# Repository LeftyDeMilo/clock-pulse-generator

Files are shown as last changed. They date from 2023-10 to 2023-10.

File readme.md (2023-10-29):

Breadboard Clock Pulse Generator with manual and automatic operating modes.
In manual mode the circuit operates as a debounced button. In automatic mode
it operates as a square wave generator. You could bear through a preset list
of frequencies in a range from 0.1 Hz to 97 Hz.

# Terminal

To check ATtiny24 fuses (and the MCU reaction) you could use `avrdude`.

```sh
$ avrdude -p t24 -c usbasp
```

Brandnew ATtiny24 _20SSU_ responses `Fuses OK (E:FF, H:DC, L:E2)`,
_20PU_ – `Fuses OK (E:FF, H:DF, L:62)`.

Preset fuses:

```sh
$ avrdude -p t24 -c usbasp -U lfuse:w:0xE2:m -U hfuse:w:0xDD:m -U efuse:w:0xFE:m
```

# Arduino IDE

Choose the proper MCU:

Tools > Board > DIY ATtiny > ATtiny24

Choose the compilation settings

Tools >

* Use Bootloader: "No (ISP Programmer Upload)"
* Processor Speed: "8MHz Internal Oscillator"
* Millis, Tone Support: "Millis Available, No Tone"
* Millis Accuracy: "Better Or Equal 0.1% Error (Highest Code Use)"
* Processor Version: "ATtiny24"
* Programmer: "DIY ATTiny: USBasp"

Upload sketch through ICSP connector using USBasp programmer:

Sketch > Upload Using Programmer

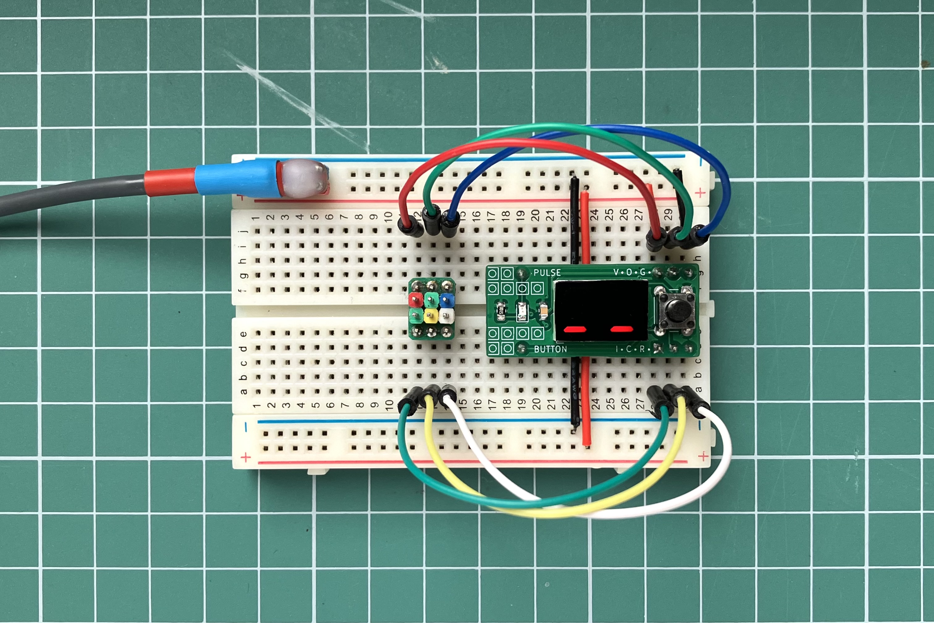
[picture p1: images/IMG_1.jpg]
ICSP Breakout Set


# Operating Manual

Use double click to change operating mode. In both modes an LED indicates a
voltage level on the PULSE pin.

### Manual mode

In manual mode the device operates as a debounced button. The seven segment
display indicates a voltage level on the PULSE pin (like an oscilloscope).

### Automatic Pulse Mode

In automatic pulse mode the display indicates a current pulse frequency.
You could bear though frequencies with a long button click.

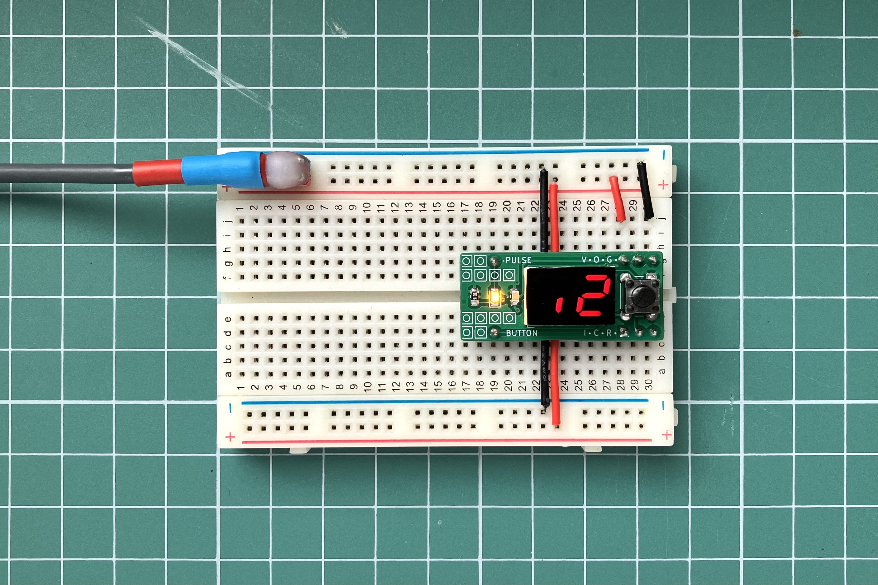
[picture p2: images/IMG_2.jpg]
Square wave pulse of 0.2 Hz


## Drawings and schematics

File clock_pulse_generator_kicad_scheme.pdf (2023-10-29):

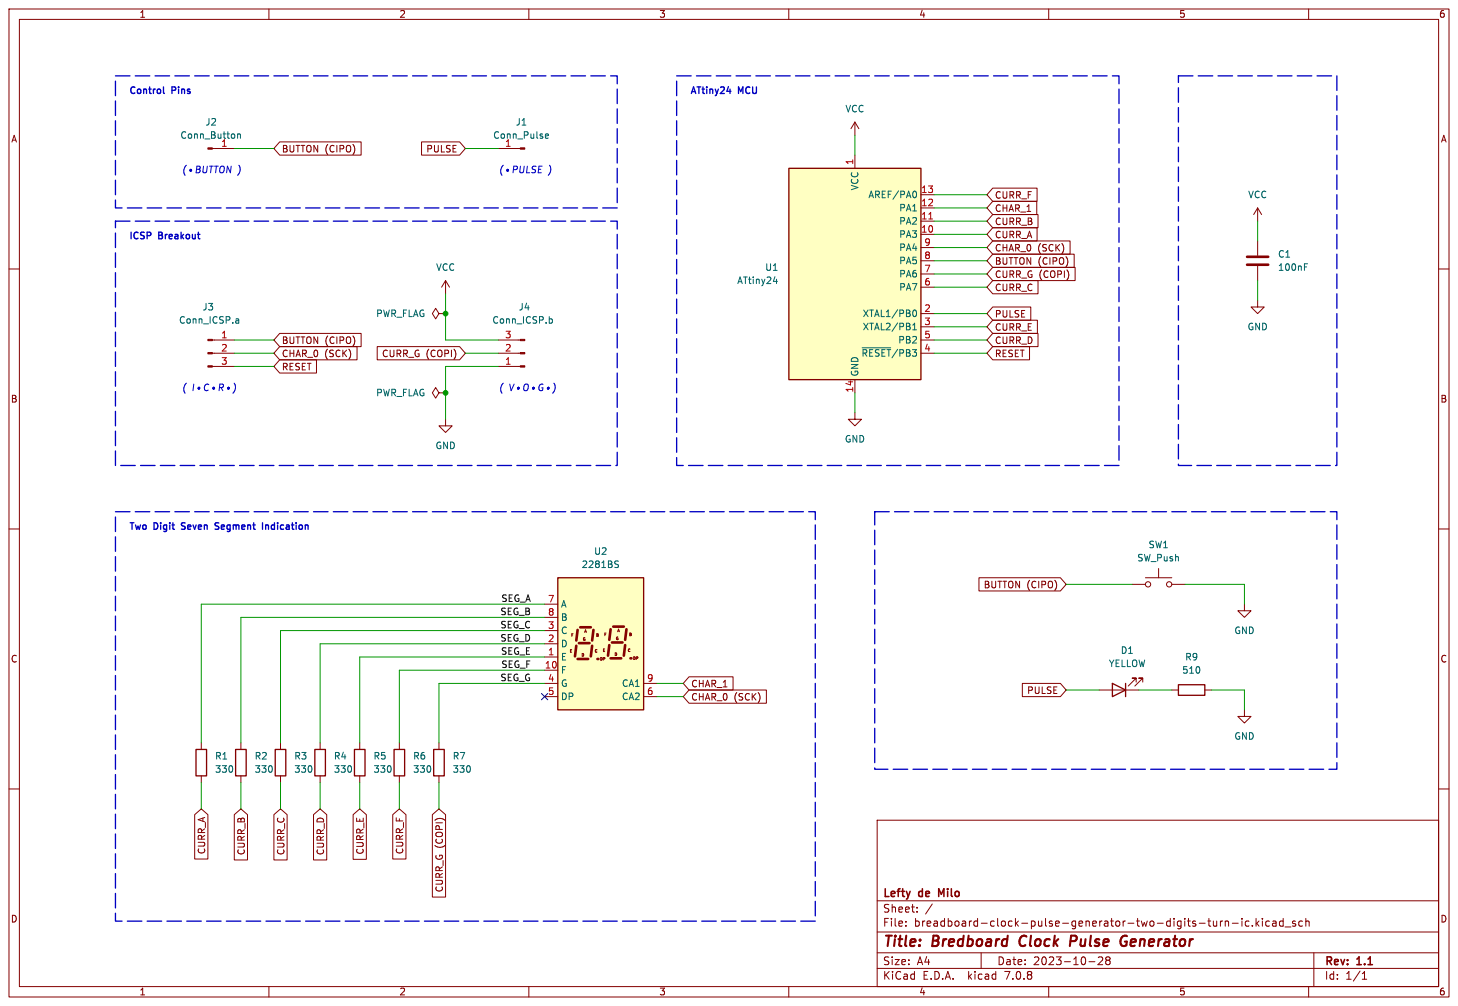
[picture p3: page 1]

CURR_B CHAR_0 (SCK) BUTTON (CIPO) CURR_G (COPI) PULSE

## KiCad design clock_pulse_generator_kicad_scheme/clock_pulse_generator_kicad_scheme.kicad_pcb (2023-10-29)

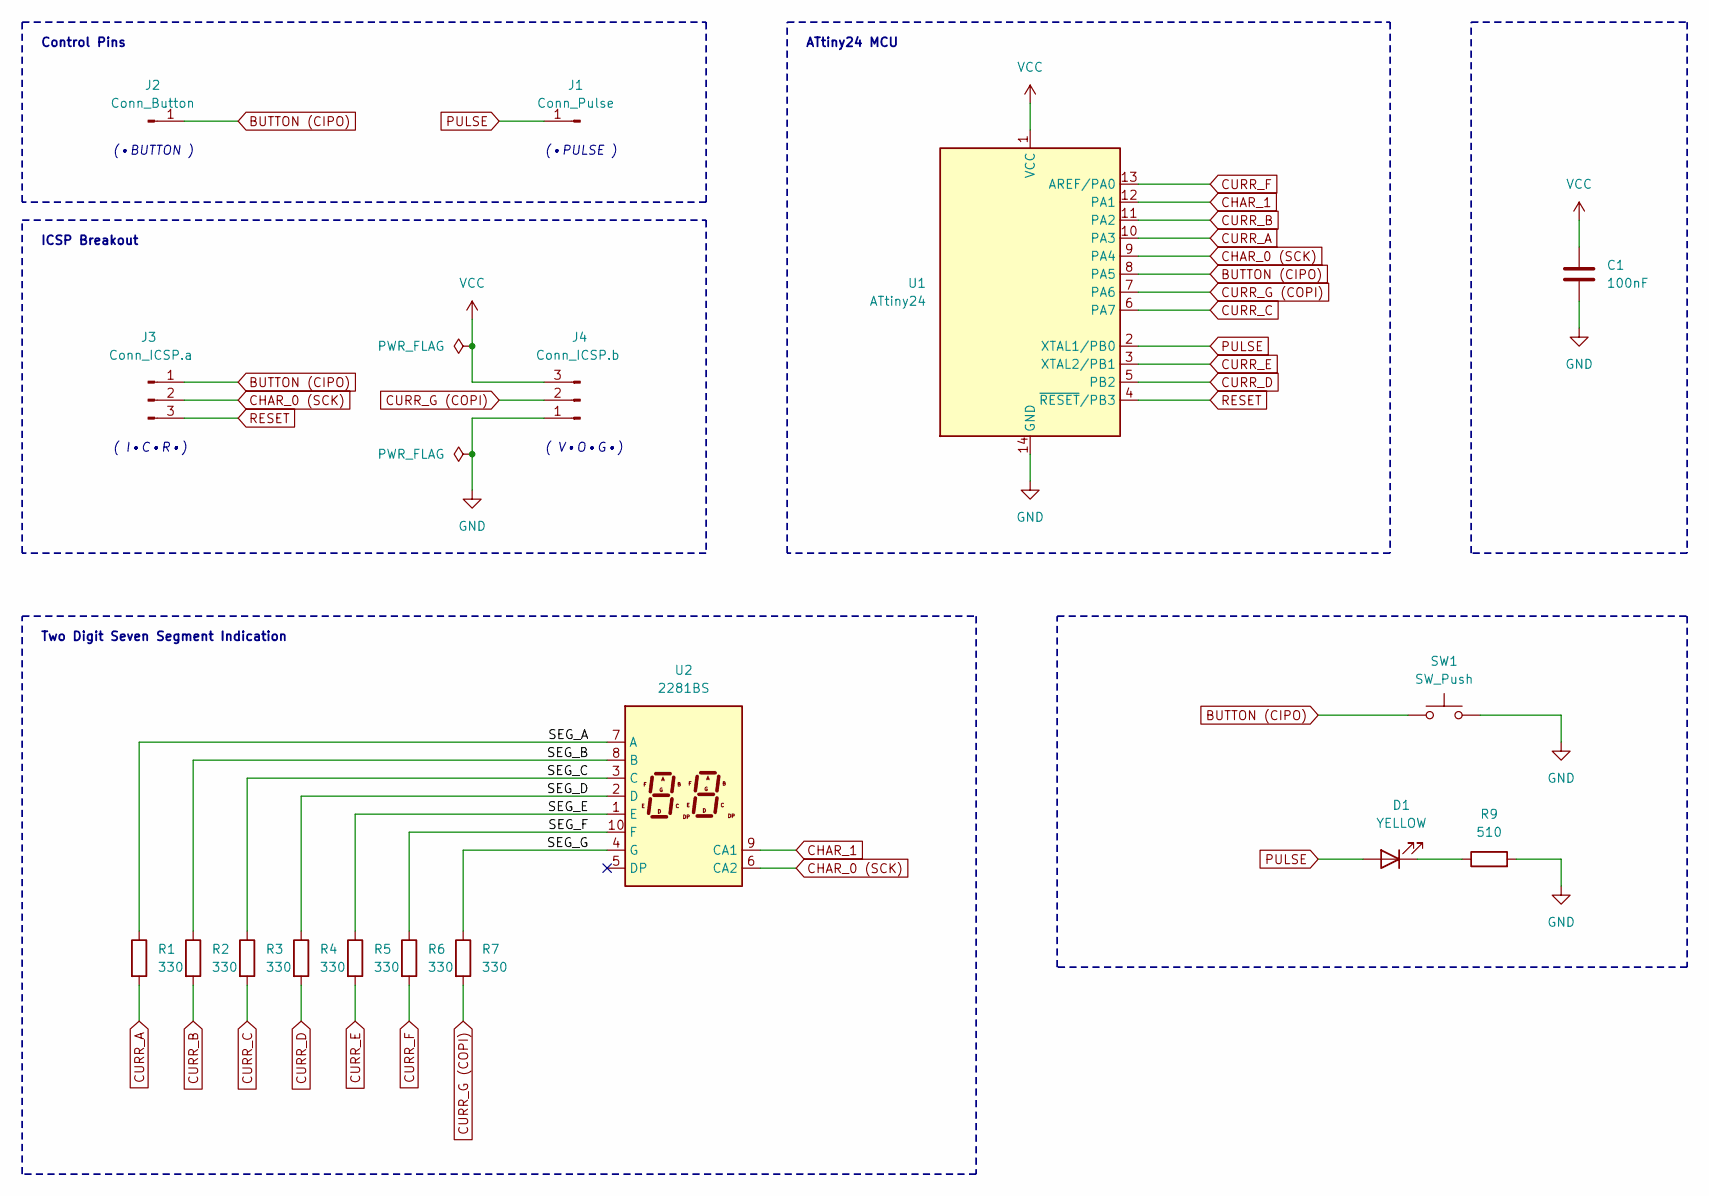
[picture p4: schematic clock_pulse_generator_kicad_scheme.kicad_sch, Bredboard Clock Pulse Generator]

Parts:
C1: 100nF; C_0805_2012Metric_Pad1.18x1.45mm_HandSolder
D1: YELLOW; LED_0805_2012Metric_Pad1.15x1.40mm_HandSolder
J1: Conn_Pulse; PinHeader_1x01_P2.54mm_Vertical
J2: Conn_Button; PinHeader_1x01_P2.54mm_Vertical
J3: Conn_ICSP.a; PinHeader_1x03_P2.54mm_Vertical
J4: Conn_ICSP.b; PinHeader_1x03_P2.54mm_Vertical
R1, R2, R3, R4, R5, R6, R7: 330; R_0805_2012Metric_Pad1.20x1.40mm_HandSolder
R9: 510; R_0805_2012Metric_Pad1.20x1.40mm_HandSolder
SW1: SW_Push; SW_PUSH_6mm_H5mm
U1: ATtiny24; SOIC-14_3.9x8.7mm_P1.27mm
U2: 2281BS; Sx39-1xxxxx

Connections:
/SEG_A: R1.1, U2.7 (A)
/SEG_B: R2.1, U2.8 (B)
/SEG_C: R3.1, U2.3 (C)
/SEG_D: R4.1, U2.2 (D)
/SEG_E: R5.1, U2.1 (E)
/SEG_F: R6.1, U2.10 (F)
/SEG_G: R7.1, U2.4 (G)
BUTTON (CIPO): J2.1, J3.1, SW1.1, U1.8 (PA5)
CHAR_0 (SCK): J3.2, U1.9 (PA4), U2.6 (CA2)
CHAR_1: U1.12 (PA1), U2.9 (CA1)
CURR_A: R1.2, U1.10 (PA3)
CURR_B: R2.2, U1.11 (PA2)
CURR_C: R3.2, U1.6 (PA7)
CURR_D: R4.2, U1.5 (PB2)
CURR_E: R5.2, U1.3 (XTAL2/PB1)
CURR_F: R6.2, U1.13 (AREF/PA0)
CURR_G (COPI): J4.2, R7.2, U1.7 (PA6)
GND: C1.2, J4.1, R9.2, SW1.2, U1.14 (GND)
unnamed: D1.1 (K), R9.1
PULSE: D1.2 (A), J1.1, U1.2 (XTAL1/PB0)
RESET: J3.3, U1.4 (~RESET/PB3)
VCC: C1.1, J4.3, U1.1 (VCC)

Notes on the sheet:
Control Pins
ICSP Breakout
ATtiny24 MCU
( V•O•G•)
(•BUTTON )
( I•C•R•)
(•PULSE )
Two Digit Seven Segment Indication

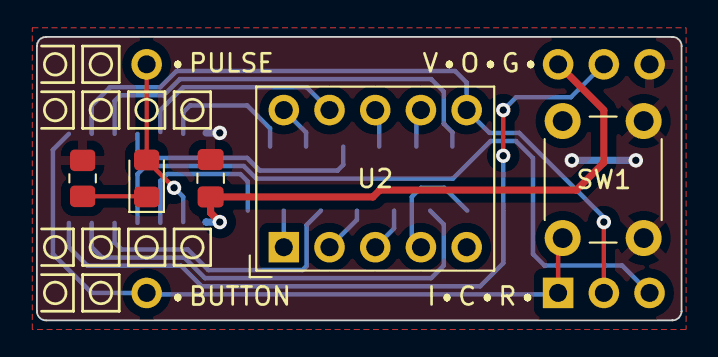
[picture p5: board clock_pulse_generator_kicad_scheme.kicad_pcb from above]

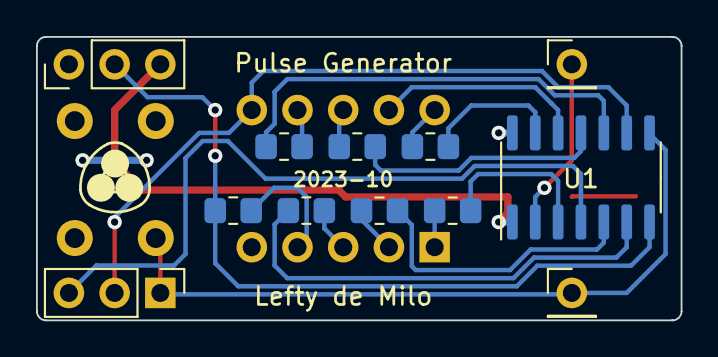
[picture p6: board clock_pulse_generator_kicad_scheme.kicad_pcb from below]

Board: 2 copper layers, 35.8 x 15.7 mm, 17 parts (12 on the bottom side), 22 nets.

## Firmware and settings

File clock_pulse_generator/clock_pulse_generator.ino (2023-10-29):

/* ATtiny24 code
 *
 * Breadboard Clock Pulse Generator with manual and automatic operating modes.
 * In manual mode the circuit operates as a debounced button. In automatic mode
 * it operates as a square wave generator. You could bear through a preset list
 * of frequencies in a range from 0.1 Hz to 97 Hz.
 */

#include "globals.h"
#include "mcuHandler.h"
#include "displayHandler.h"
#include "buttonHandler.h"

void setup() {

  pinMode(mcu::BUTTON, INPUT_PULLUP);
  pinMode(mcu::OUTPUT_SIGNAL, OUTPUT);
  pinMode(mcu::SEG_a, OUTPUT);
  pinMode(mcu::SEG_b, OUTPUT);
  pinMode(mcu::SEG_c, OUTPUT);
  pinMode(mcu::SEG_d, OUTPUT);
  pinMode(mcu::SEG_e, OUTPUT);
  pinMode(mcu::SEG_f, OUTPUT);
  pinMode(mcu::SEG_g, OUTPUT);
  pinMode(mcu::CHAR_0, OUTPUT);
  pinMode(mcu::CHAR_1, OUTPUT);

  delay(1);

  // Manual mode indication
  display::setChars(symbol::OVERSCORE, symbol::OVERSCORE);

}

void loop() {

  button::handler();
  display::handler();

}

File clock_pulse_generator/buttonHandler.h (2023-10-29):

#ifndef BUTTON_HANDLER_H
#define BUTTON_HANDLER_H

#include "globals.h"
#include "displayHandler.h"

namespace button {

namespace {

constexpr uint32_t _DOUBLE_TAP_DELAY = 256;
constexpr uint32_t _LONG_TAP_DELAY = 1024;

// Button states patterns
constexpr uint8_t _PRESSED = 0b10000000;
constexpr uint8_t _RELEASED = 0b01111111;

uint32_t _buttonEventTime = 0;

}

uint8_t bounceSequence() {
  static uint8_t sequence;
  sequence = (sequence << 1) | digitalRead(mcu::BUTTON);
  return sequence;
}

void manual_mode_handler() {
  uint32_t handleTime = millis();
  if (buttonPressed) {
    digitalWrite(mcu::OUTPUT_SIGNAL, HIGH);
  } else {
    digitalWrite(mcu::OUTPUT_SIGNAL, LOW);
  }
  if(ANIMATION_MODE) {
    display::manualModeAnimation(handleTime - _buttonEventTime);
  } else {
    display::manualModeDisplay();
  }
}

void auto_mode_handler(bool longPress) {
  static uint16_t count = 0;
  static uint8_t speedModeLag = 0;
  static uint8_t bandIndex = mcu::INIT_INDEX;
  uint16_t value = mcu::MILLIS_VALUES[bandIndex][1];
  if (longPress) {
    if (speedModeLag > 3) {
      if (millis() / (_DOUBLE_TAP_DELAY / 2) & 1) {
        if (count == 0) bandIndex = (bandIndex + 1) % mcu::BANDS;
        count++;
      } else {
        count = 0;
      }
      display::buffer = value;
    } else {
      if (millis() / _DOUBLE_TAP_DELAY & 1) {
        display::clear();
      } else {
        display::buffer = value;
      }
      if (millis() / (_DOUBLE_TAP_DELAY * 2) & 1) {
        if (count == 0) {
          bandIndex = (bandIndex + 1) % mcu::BANDS;
          speedModeLag++;
        }
        count++;
      } else {
        count = 0;
      }
    }
  } else {
    count = 0;
    speedModeLag = 0;
    display::buffer = value;
  }
  digitalWrite(
    mcu::OUTPUT_SIGNAL,
    millis() / mcu::MILLIS_VALUES[bandIndex][0] & 1);
}

void handler() {
  static uint8_t quickTapsCount = 0;
  static bool longPress = false;
  uint8_t sequence = bounceSequence();
  if (sequence == _PRESSED) {
    _buttonEventTime = millis();
    buttonPressed = true;
    quickTapsCount++;
    if (quickTapsCount == 2) {
      mcu::manualMode = !mcu::manualMode;
      quickTapsCount = 0;
    }
  }
  if (sequence == _RELEASED) {
    _buttonEventTime = millis();
    buttonPressed = false;
    longPress = false;
  }
  if (millis() - _buttonEventTime > _DOUBLE_TAP_DELAY) {
    quickTapsCount = 0;
  }
  if (buttonPressed && (millis() - _buttonEventTime > _LONG_TAP_DELAY)) {
    longPress = true;
  }
  if (mcu::manualMode) manual_mode_handler();
  else auto_mode_handler(longPress);
}

}  // button namespace

#endif
